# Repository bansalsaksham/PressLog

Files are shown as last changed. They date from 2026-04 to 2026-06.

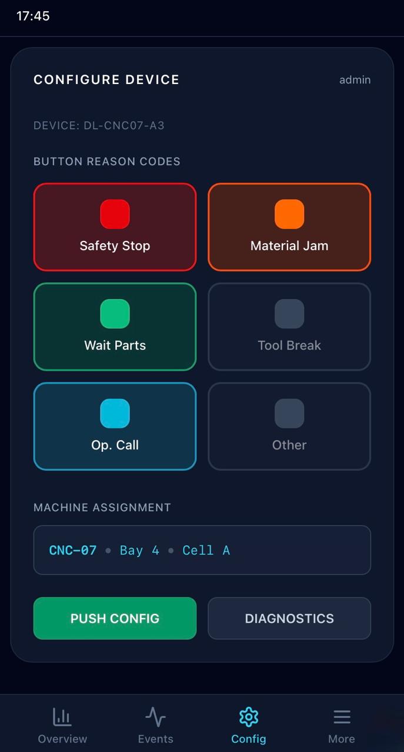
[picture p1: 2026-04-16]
Documentation/Screen 2.jpeg

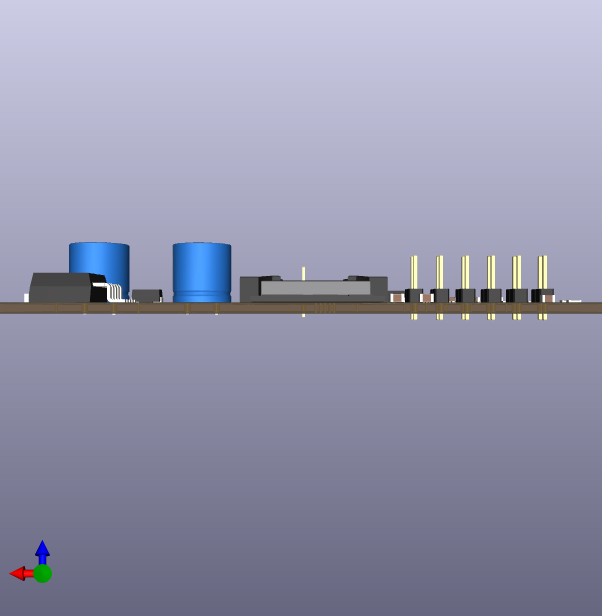
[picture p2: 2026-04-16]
Documentation/PressLog_Side.png

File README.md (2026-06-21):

# PressLog — Industrial IoT OEE Downtime Logger

A manufacturing-ready PCB and firmware architecture for capturing machine downtime reasons on a factory floor.

> **Origin:** The original design brief (see `Original Case Study Brief.pdf`) was given as a second-round technical case study during an internship interview process. I completed the full PCB design and firmware architecture independently and am sharing it here as my own project.

> **Status:** PCB design and firmware architecture complete. DRC/ERC clean, Gerbers and BOM generated for fabrication. Not yet physically built/soldered — this repository documents the design and engineering rationale, not a deployed product.

---

## 1. The Problem

OEE (Overall Equipment Effectiveness) is only as good as its data. But capturing downtime reasons at the machine edge is a human-interface problem as much as a software one. The factory floor kills conventional UX.

| Constraint | Root Cause | Why Standard Solutions Fail |
|---|---|---|
| **Gloved hands** | Thick Kevlar + metallic dust make capacitive screens useless | Tablet solutions require bare fingers: 15–30s to glove off/on. Fails the 5-second window. |
| **Patchy Wi-Fi** | VFDs, metal shielding, and RF interference create 2-hour dead zones | Cloud-first designs lose events silently. Operator never knows. OEE has invisible gaps. |
| **5-second window** | Operator moves to the next task seconds after a machine stops | Any UI requiring navigation or multiple confirmations is abandoned. |

## 2. Design Philosophy

- **Physical First** — Six large 30mm illuminated tactile buttons, one per reason code. No menus, no navigation, no scrolling. One press = one logged event, confirmed by an LED flash, an 85dB buzzer, and vibration.
- **Offline First** — Every press is timestamped via a DS3231 RTC and written to 8MB LittleFS flash *before* any network attempt. When Wi-Fi returns, the device silently replays the queue.
- **OEE Ready** — Each event carries `device_id`, `machine_id`, `reason_code`, `operator_uid` (NFC badge tap), UTC timestamp, and a sequence number. Sequence gaps are auto-detected downstream so any connectivity hole is visible to plant management.

## 3. Hardware — Custom 2-Layer PCB (KiCad)

Designed specifically for high-noise industrial environments.

| Engineering Decision | Why It Matters |
|---|---|
| **RC hardware debounce matrix** (10kΩ/0.1µF) on all 6 inputs | Software-only debouncing fails near VFDs and heavy machinery — this prevents ghost button events at the hardware level |
| **Isolated I2C routing for DS3231 RTC** | Routed completely clear of the 150kHz buck converter switching node — prevents inductive noise from corrupting timestamps. If the timestamp is wrong, the offline queue is worthless. |
| **DFM: thermal vias 0.2mm → 0.3mm** | Standard drill size reduces fabrication cost without sacrificing thermal performance |
| **RF-notched board edge** | Lets the ESP32 antenna hang off the fiberglass substrate, preventing signal attenuation |

### Physical Specifications

| Component | Specification |
|---|---|
| Platform | ESP32-S3, dual-core 240MHz |
| Buttons | 6× 30mm illuminated tactile (5N actuation) |
| Connectivity | Wi-Fi 802.11n + BLE 5.0 |
| Offline queue | 8MB LittleFS (~65,000 events) |
| RTC | DS3231, ±2ppm, coin-cell backup |
| Power | 24VDC input + 2000mAh LiPo backup (8h) |
| Identity | PN532 NFC module |

## 4. Firmware Architecture

**Offline-first data flow:**
```
Button Press → RTC Timestamp → Flash Queue (always written first) → Wi-Fi Check → Cloud Sync (batch HTTPS POST)
```

Defense-in-depth: the hardware RC filter kills high-frequency spikes; a 50ms software debounce is the secondary safety net.

```cpp
// Button ISR with secondary 50ms software debounce
void IRAM_ATTR isr_btn_0() {
  uint32_t now = millis();
  if (!pressed[0] && (now - last[0]) > 50) {
    pressed[0] = true;
    last[0] = now;
  }
}

// Queue write — always before network attempt
queueWrite(seq, rtc.now().unixtime(), buttonIdx); // flash first
confirmFeedback(buttonIdx);                       // LED + buzzer + vibration
if (wifiOnline) syncQueue();                       // attempt immediate sync
```

**Event payload schema:**
```json
{
  "device_id": "DL-CNC07-A3",
  "seq": 1042,
  "ts": "2026-04-08T14:22:08Z",
  "ts_source": "rtc",
  "reason_code": "MATERIAL_JAM",
  "reason_label": "Material Jam",
  "operator_uid": "a3f9d82c",
  "machine_id": "CNC-07"
}
```

## 5. Repository Structure

```
├── Hardware_Source/          # KiCad project — schematics + PCB layout
│   ├── ESP32_Core.kicad_sch
│   ├── HMI_IO.kicad_sch
│   ├── Power_Delivery.kicad_sch
│   ├── RTC_SubSystem.kicad_sch
│   └── PressLog_Edge_Node.kicad_pcb / .kicad_pro
├── Manufacturing/            # Fabrication-ready outputs
│   ├── PressLog_Gerbers/
│   └── PressLog_BOM.csv
├── Documentation/            # Renders, design rule reports, app mockups
│   ├── PressLog_Edge_Node.pdf
│   ├── DRC.rpt / ERC.rpt    # Design Rule Check / Electrical Rule Check — board is verified manufacturable
│   ├── PressLog_Front.png / _Back.png / _Side.png
│   └── App Interface Designs.pdf
└── Original Case Study Brief.pdf   # Full original case study writeup
```

## 6. What's Verified vs. Designed-Only

- ✅ Schematic capture across 4 subsystems (ESP32 core, HMI/IO, power delivery, RTC)
- ✅ PCB layout, routed and DRC/ERC clean
- ✅ Gerbers + BOM generated — ready to send to a fab house
- ⬜ Physical assembly / soldering — not yet built
- ⬜ Firmware — architecture and key patterns designed; not yet flashed to hardware

This was a design and engineering reasoning exercise, not a built product. The PCB design itself is real, complete, and manufacturable.

---

**Tools used:** KiCad, ESP32-S3, LittleFS, DS3231 RTC, PN532 NFC

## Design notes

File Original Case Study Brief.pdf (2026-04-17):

## Traction: Innovation Case Study

Submitted By: Saksham Bansal
GitHub Repo: https://github.com/bansalsaksham/Traction

The Problem:

OEE is only as good as its data. But capturing downtime reasons at the machine edge is a humaninterface problem as much as a software one. The factory floor kills conventional UX.
Constraint | Root Cause | Why standard solutions fail
Gloved Hands | Thick Kevlar + metallic dust make capacitive screens useless | Tablet solutions require bare fingers: 15-30s to glove off/on. Fails the 5-second window.
Patchy Wi-Fi | VFDs, metal shielding, and RF interference create 2-hour dead zones | Cloud-first designs lose events silently. Operator never knows. OEE has invisible gaps.
5-Second window | Operator moves to the next task seconds after a machine stops | Any UI requiring navigation or multiple confirmations will simply be abandoned.

Design Philosophy:

1. Physical First: Six large 30mm illuminated tactile buttons; one per reason code. No menus, no navigation, no scrolling. One press = one logged event, confirmed by an LED flash, an 85 dB buzzer, and vibration.
2. Offline First: Every press is timestamped via a DS3231 RTC and written to an 8 MB LittleFS flash BEFORE any network attempt. When Wi-Fi returns, the device silently replays the queue. The operator never needs to care whether they are online.
3. OEE Ready: Each event carries: device_id, machine_id, reason_code, operator_uid (NFC badge tap), UTC timestamp, and a sequence number. Tractian-compatible JSON. Sequence gaps are auto detected by the dashboard so any connectivity hole is visible to plant management.

Custom Hardware Implementation (PCB):

To meet the physical constraints of a machine shop, I designed a custom, manufacturing-ready 2-layer PCB in KiCad specifically engineered for high-noise industrial environments.

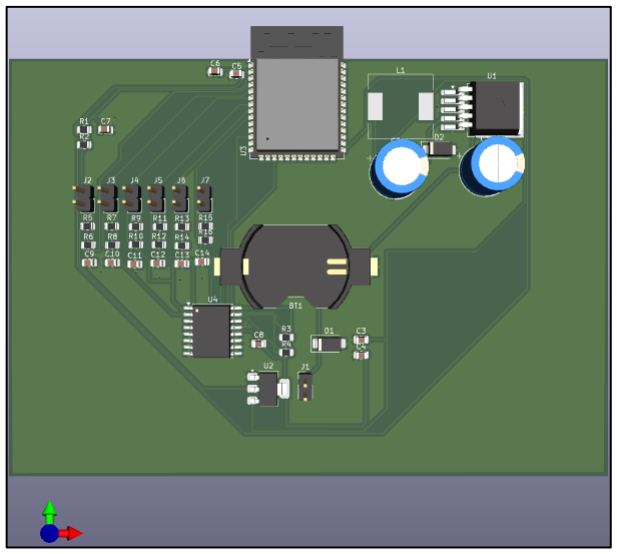
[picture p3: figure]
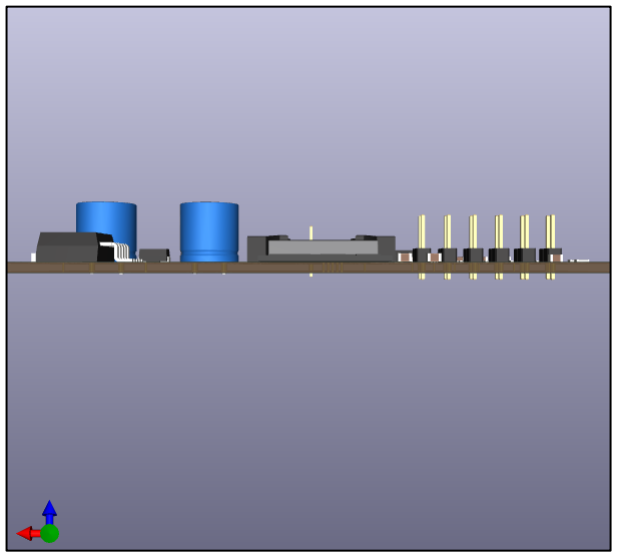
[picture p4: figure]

- Engineering for the Factory Floor:
- Hardware Debouncing (EMI Immunity): Relying on software debouncing in an environment with Variable Frequency Drives (VFDs) and heavy machinery can lead to false triggers. I designed a dedicated RC hardware debounce matrix (10kΩ/0.1µF) for all six inputs. This provides a clean, stable signal to the ESP32-S3 before processing occurs, preventing ghost events.
- Isolated Timekeeping: The core value of this device is the offline queue. If the timestamp is corrupted, the data is useless. I routed the I2C communication lines for the DS3231 RTC completely isolated from the 150kHz switching node of the onboard buck converter to prevent inductive noise interference.
- Design for Manufacturing (DFM): The board was designed for cost-effective production. I overrode the standard ESP32 footprint, expanding the thermal vias from a costly 0.2mm drill size to a standard 0.3mm, reducing fabrication costs without sacrificing thermal performance.
- RF Optimization: The board edge is specifically notched to allow the ESP32 antenna to hang off the fiberglass substrate, preventing signal attenuation and maximizing connectivity.

- Physical Specifications:
Platform | ESP32-S3 dual-core 240 MHz
Buttons | 6 x 30mm illuminated tactile (5N actuation)
Connectivity | Wi-Fi 802.11n + BLE 5.0
Offline Queue | 8 MB LittleFS (~65,000 events)
RTC | DS3231 ±2 ppm, coin-cell backup
Power | 24 VDC input + 2000 mAh LiPo backup (8h)
Identity | PN532 NFC module

Software & Firmware:

- Data Flow: Offline First Architecture

Events are written to flash BEFORE any network attempt. Zero data loss regardless of connectivity.

- Firmware: Key Patterns
- Button ISR with 50 ms hardware debounce:
- Queue write; always before network attempt:

Button Press
(Hardware
Event)

RTC
Timestamp
(UTC ISO-8601)

Flash Queue
(always written
first)

Wi-Fi Check
(Online /
Offline)

Cloud Sync
(batch HTTPS
POST)

void IRAM_ATTR isr_btn_0() { uint32_t now = millis();
if (!pressed[0] && (now - last[0]) > 50) { pressed[0] = true;
last[0] = now;
}}

queueWrite(seq, rtc.now().unixtime(), buttonIdx); // flash first confirmFeedback(buttonIdx); // LED + buzzer + vibration
if (wifiOnline) syncQueue(); // attempt immediate sync

- JSON event payload schema:
- Web Dashboard: The Three Screens

The data collected by the edge node seamlessly populates the Tractian software environment, providing plant managers with actionable insights.

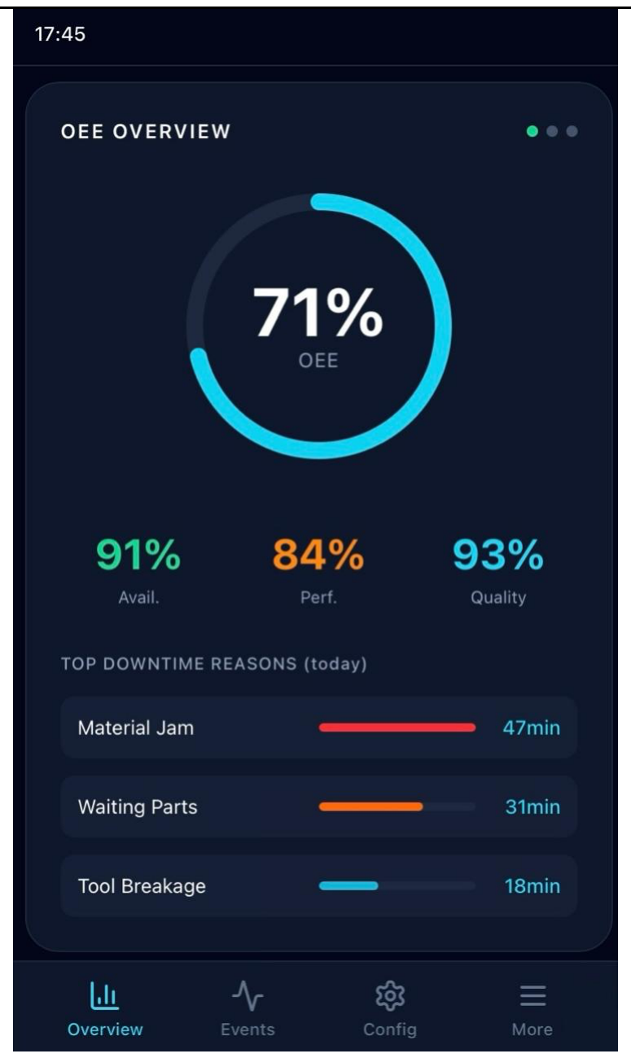
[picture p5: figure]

OEE Overview: Breaks down incoming data into true Availability, Performance, and Quality metrics, calculating the financial impact of the specific downtime reasons captured by the edge nodes.

{ "device_id": "DL-CNC07-A3", "seq": 1042,
"ts": "2026-04-08T14:22:08Z", "ts_source": "rtc",
"reason_code": "MATERIAL_JAM", "reason_label": "Material Jam", "operator_uid": "a3f9d82c", "machine_id": "CNC-07" }

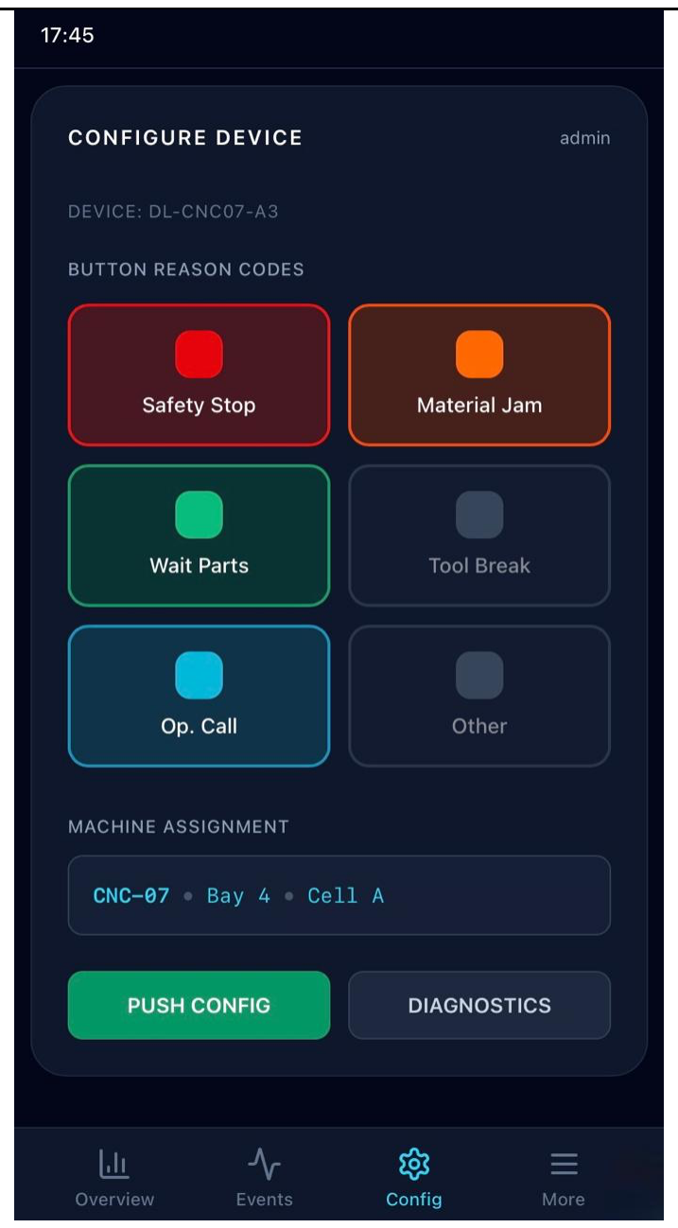
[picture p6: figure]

Device Configuration: Allows managers to assign color-coded reason codes remotely. This pushes OTA updates to the physical 6-button node on the factory floor, mapping the physical buttons to logical software categories.

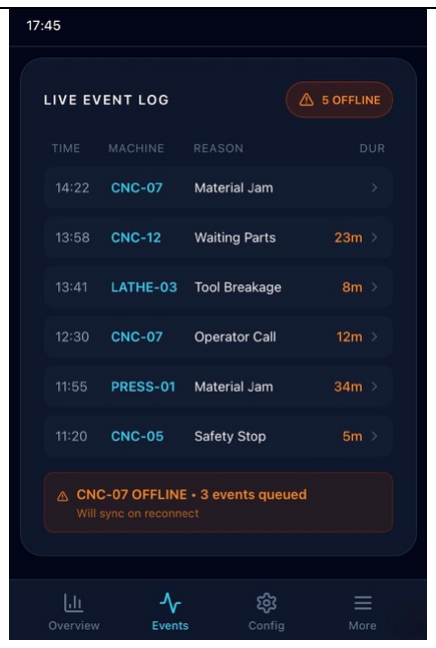
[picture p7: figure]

Live Event Log: A real-time feed of logged stops. Crucially, offline devices (like CNC-07) are clearly flagged with their queued event counts, proving the system architecture handles 2-hour network drops gracefully.

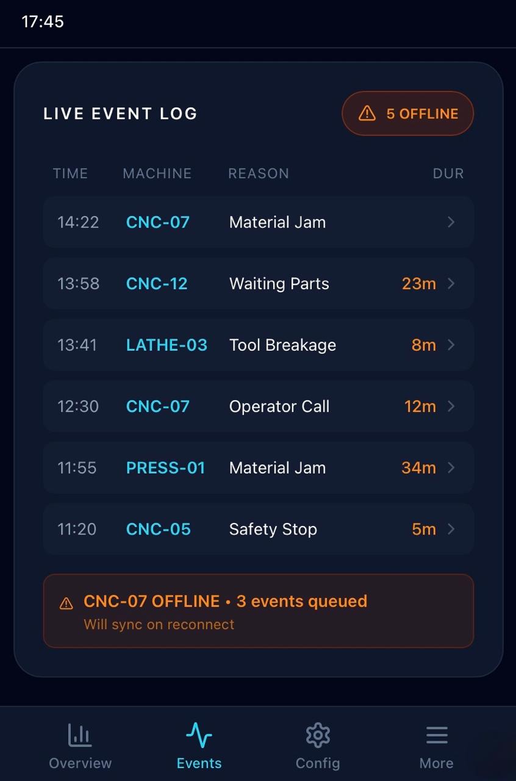
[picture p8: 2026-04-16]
Documentation/Screen 3.jpeg

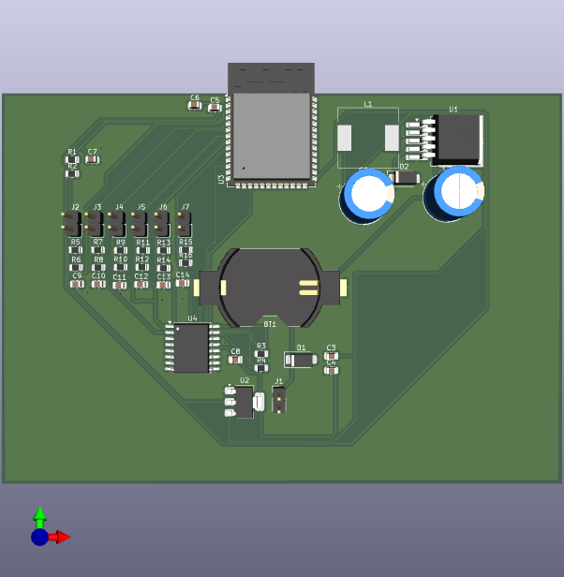
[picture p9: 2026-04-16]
Documentation/PressLog_Front.png

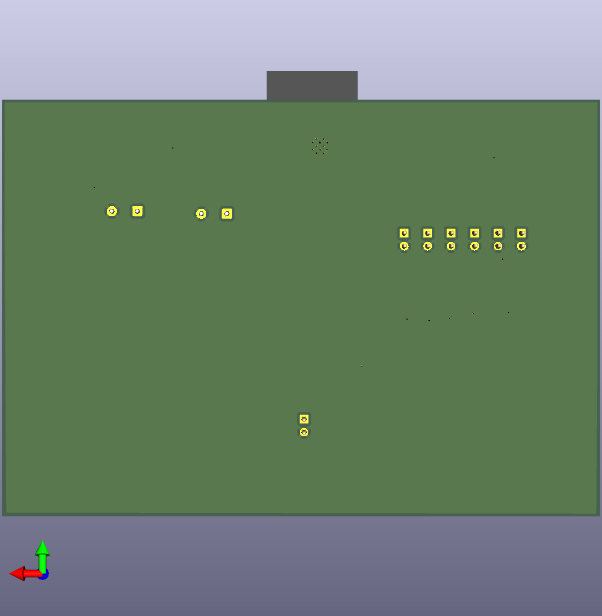
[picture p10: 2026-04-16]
Documentation/PressLog_Back.png

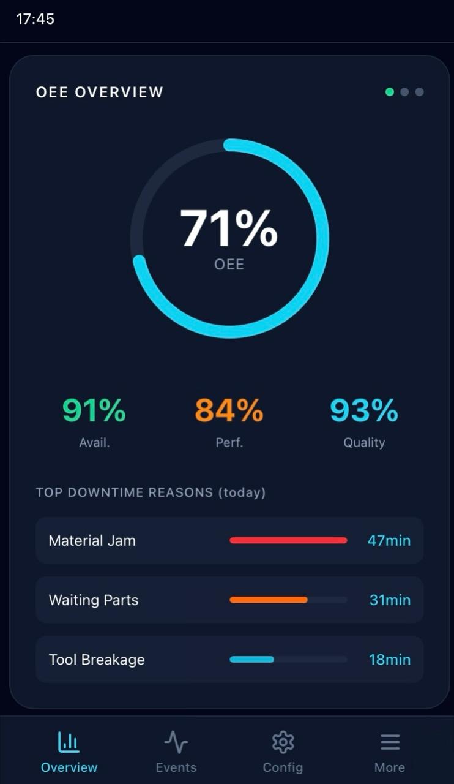
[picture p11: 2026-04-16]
Documentation/Screen 1.jpeg

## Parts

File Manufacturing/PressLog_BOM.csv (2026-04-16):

Reference | Qty | Value | DNP | Exclude from BOM | Exclude from Board | Footprint | Datasheet
BT1 | 1 | Battery_Cell |  |  |  | Battery:BatteryHolder_Keystone_1058_1x2032 | ~
C1 | 1 | 100uF |  |  |  | Capacitor_THT:CP_Radial_D10.0mm_P5.00mm | ~
C2 | 1 | 220uF |  |  |  | Capacitor_THT:CP_Radial_D10.0mm_P5.00mm | ~
C3,C4,C5 | 3 | 10uF |  |  |  | Capacitor_SMD:C_0805_2012Metric | ~
C6,C8,C9,C10,C11,C12,C13,C14 | 8 | 0.1uF |  |  |  | Capacitor_SMD:C_0805_2012Metric | ~
C7 | 1 | 1uF |  |  |  | Capacitor_SMD:C_0805_2012Metric | ~
D1 | 1 | D_TVS |  |  |  | Diode_SMD:D_SMA | ~
D2 | 1 | D_Schottky |  |  |  | Diode_SMD:D_SMA | ~
J1,J2,J3,J4,J5,J6,J7 | 7 | Conn_01x02 |  |  |  | Connector_PinHeader_2.54mm:PinHeader_1x02_P2.54mm_Vertical | ~
L1 | 1 | 33uH |  |  |  | Inductor_SMD:L_12x12mm_H6mm | ~
R1,R2 | 2 | 10kΩ |  |  |  | Resistor_SMD:R_0805_2012Metric | ~
R3,R4 | 2 | 4.7k |  |  |  | Resistor_SMD:R_0805_2012Metric | ~
R5,R6,R7,R8,R9,R10,R11,R12,R13,R14,R15,R16 | 12 | 10k |  |  |  | Resistor_SMD:R_0805_2012Metric | ~
U1 | 1 | LM2596S-5 |  |  |  | Package_TO_SOT_SMD:TO-263-5_TabPin3 | http://www.ti.com/lit/ds/symlink/lm2596.pdf
U2 | 1 | AMS1117 |  |  |  | Package_TO_SOT_SMD:SOT-223-3_TabPin2 | http://www.advanced-monolithic.com/pdf/ds1117.pdf
U3 | 1 | ESP32-S3-WROOM-1 |  |  |  | RF_Module:ESP32-S3-WROOM-1 | https://www.espressif.com/sites/default/files/documentation/esp32-s3-wroom-1_wroom-1u_datasheet_en.pdf
U4 | 1 | DS3231M |  |  |  | Package_SO:SOIC-16W_7.5x10.3mm_P1.27mm | http://datasheets.maximintegrated.com/en/ds/DS3231.pdf

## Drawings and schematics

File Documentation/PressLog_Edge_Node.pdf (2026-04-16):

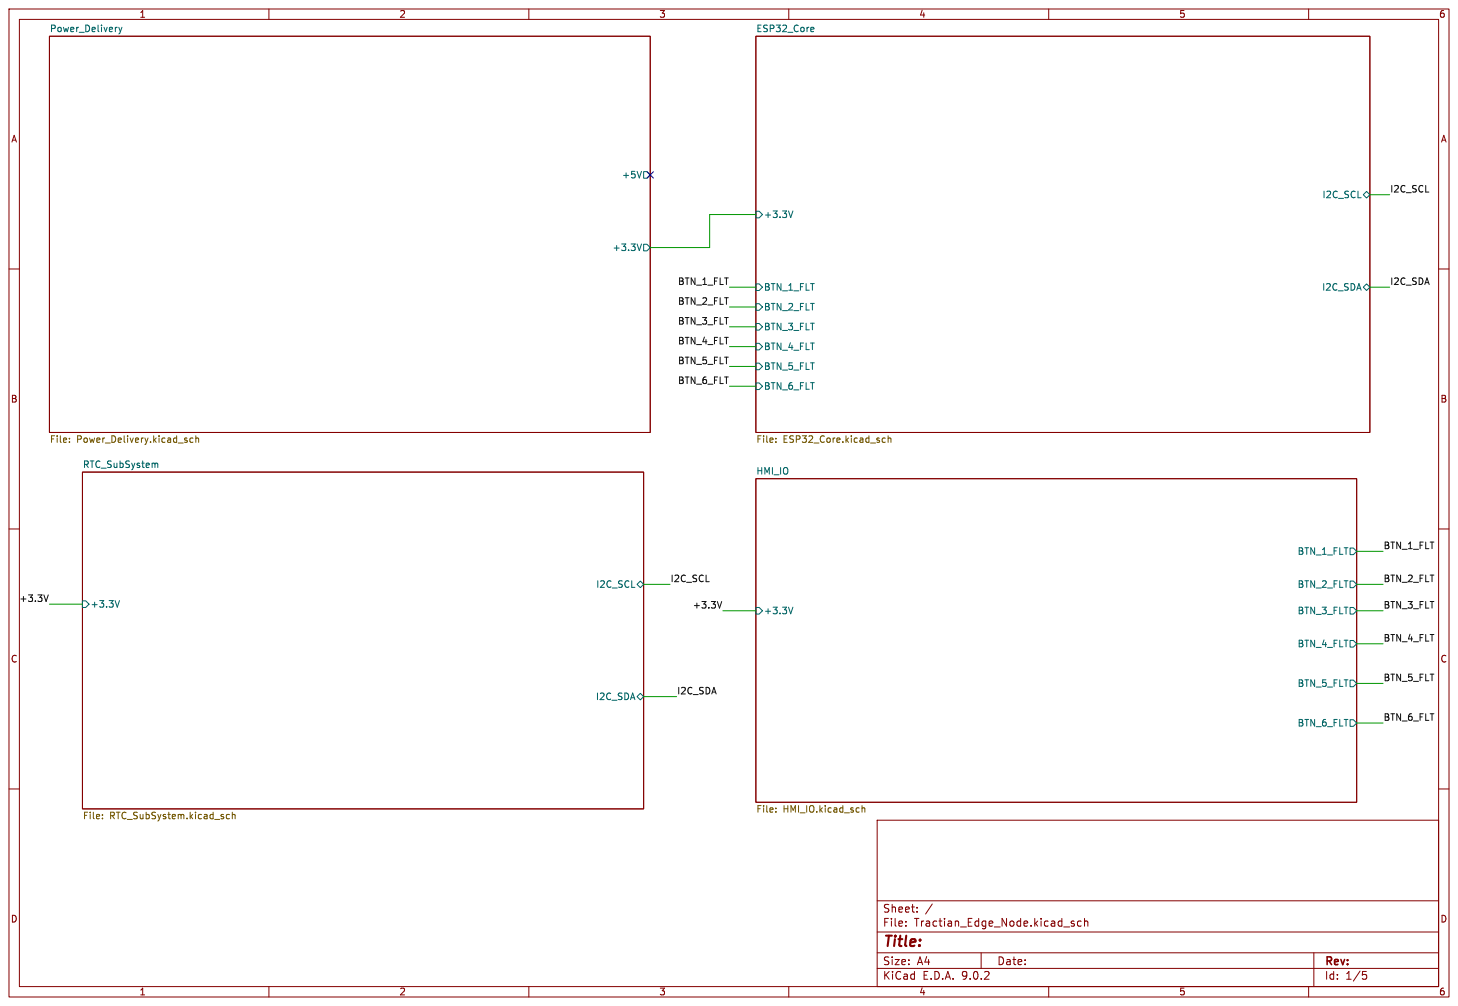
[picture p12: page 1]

Id: 1/5 Title: File: Tractian_Edge_Node.kicad_sch Sheet: / +3.3V

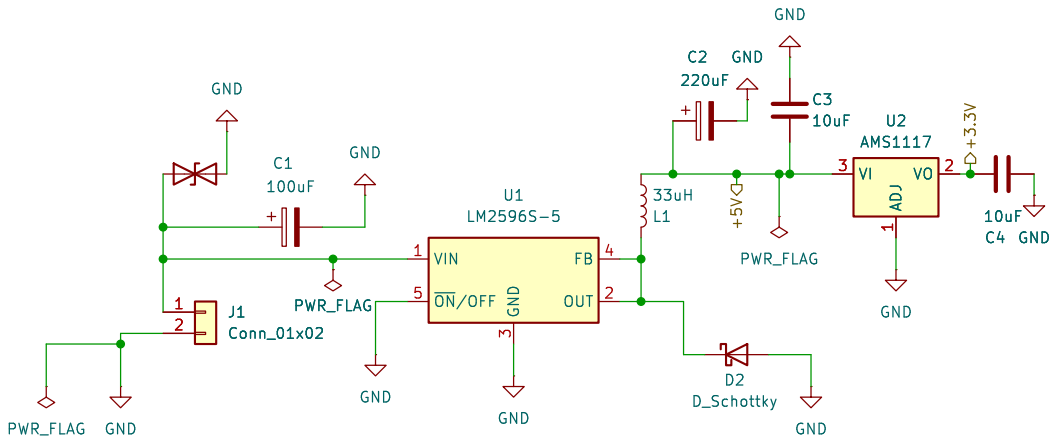
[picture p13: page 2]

Id: 2/5 Title: File: Power_Delivery.kicad_sch Sheet: /Power_Delivery/

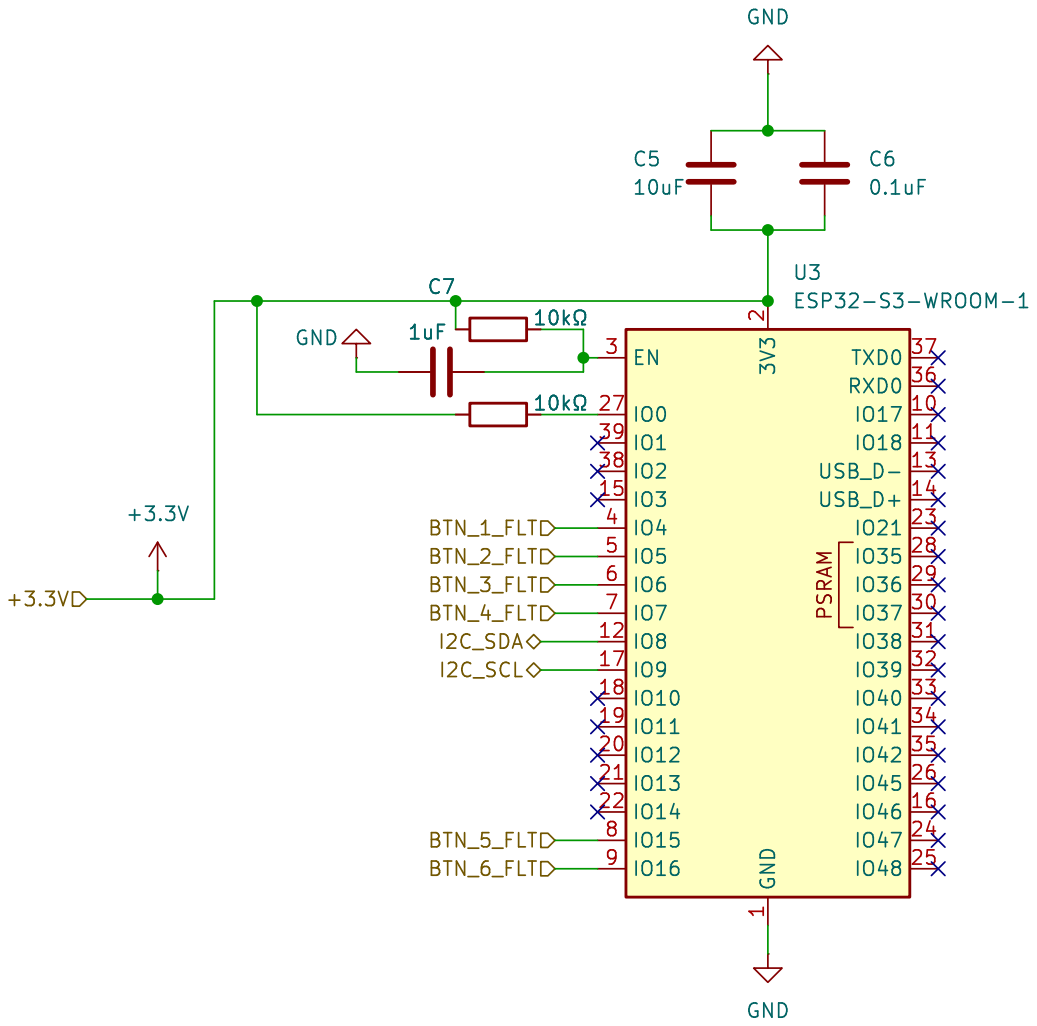
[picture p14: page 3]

Id: 3/5 Title: File: ESP32_Core.kicad_sch Sheet: /ESP32_Core/

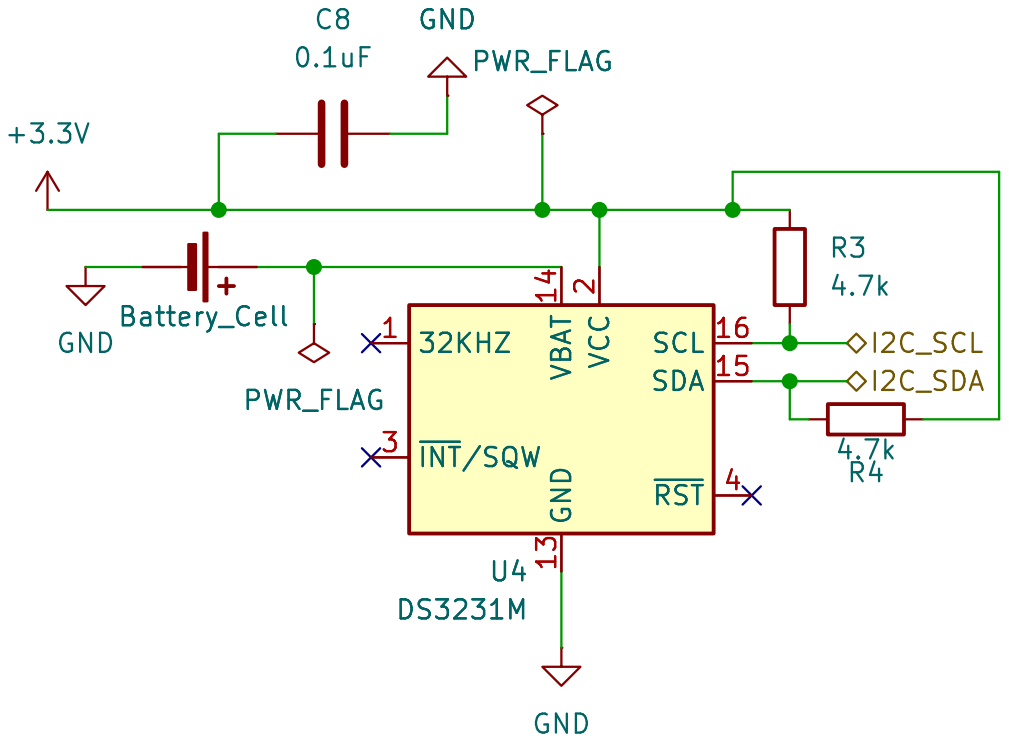
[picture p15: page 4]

Id: 4/5 Title: File: RTC_SubSystem.kicad_sch Sheet: /RTC_SubSystem/

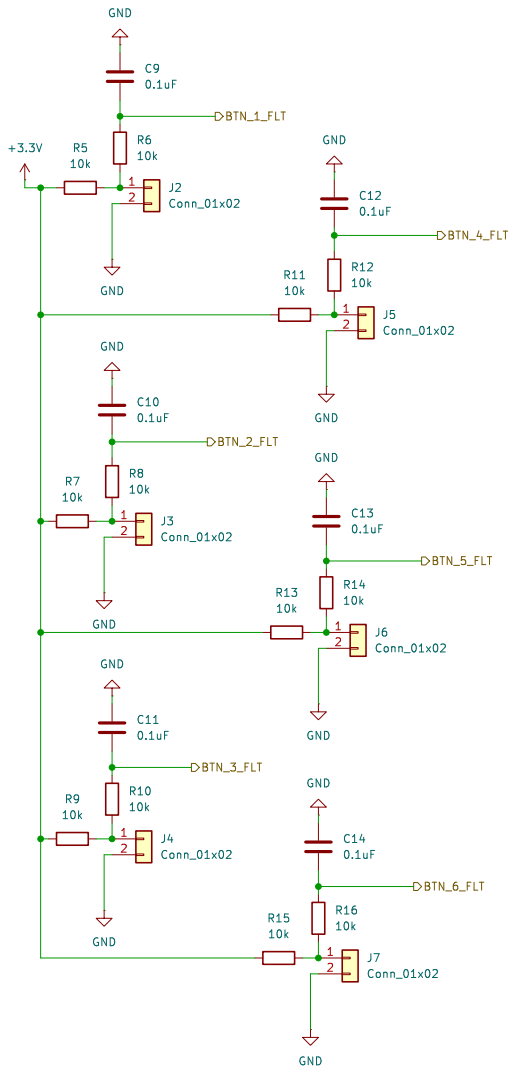
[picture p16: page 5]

Id: 5/5 Title: File: HMI_IO.kicad_sch Sheet: /HMI_IO/ GND GND 12

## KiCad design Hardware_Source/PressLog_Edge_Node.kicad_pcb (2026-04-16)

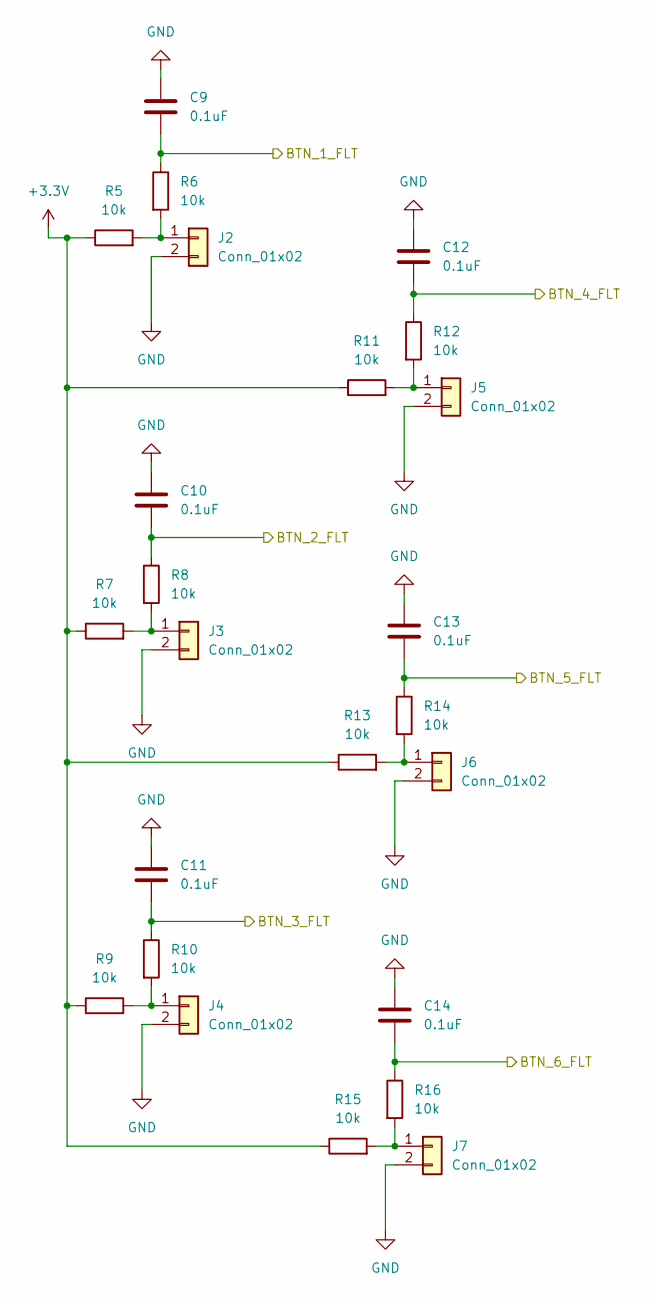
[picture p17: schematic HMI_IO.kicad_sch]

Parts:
C9, C10, C11, C12, C13, C14: 0.1uF; C_0805_2012Metric
J2, J3, J4, J5, J6, J7: Conn_01x02; PinHeader_1x02_P2.54mm_Vertical
R5, R6, R7, R8, R9, R10, R11, R12, R13, R14, R15, R16: 10k; R_0805_2012Metric

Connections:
+3.3V: R5.1, R7.1, R9.1, R11.1, R13.1, R15.1; also elsewhere on the board
/BTN_1_FLT: C9.2, R6.1; also elsewhere on the board
/BTN_2_FLT: C10.2, R8.1; also elsewhere on the board
/BTN_3_FLT: C11.2, R10.1; also elsewhere on the board
/BTN_4_FLT: C12.2, R12.1; also elsewhere on the board
/BTN_5_FLT: C13.2, R14.1; also elsewhere on the board
/BTN_6_FLT: C14.2, R16.1; also elsewhere on the board
GND: C9.1, C10.1, C11.1, C12.1, C13.1, C14.1, J2.2, J3.2, J4.2, J5.2, J6.2, J7.2; also elsewhere on the board
unnamed: J2.1, R5.2, R6.2
unnamed: J3.1, R7.2, R8.2
unnamed: J4.1, R9.2, R10.2
unnamed: J5.1, R11.2, R12.2
unnamed: J6.1, R13.2, R14.2
unnamed: J7.1, R15.2, R16.2

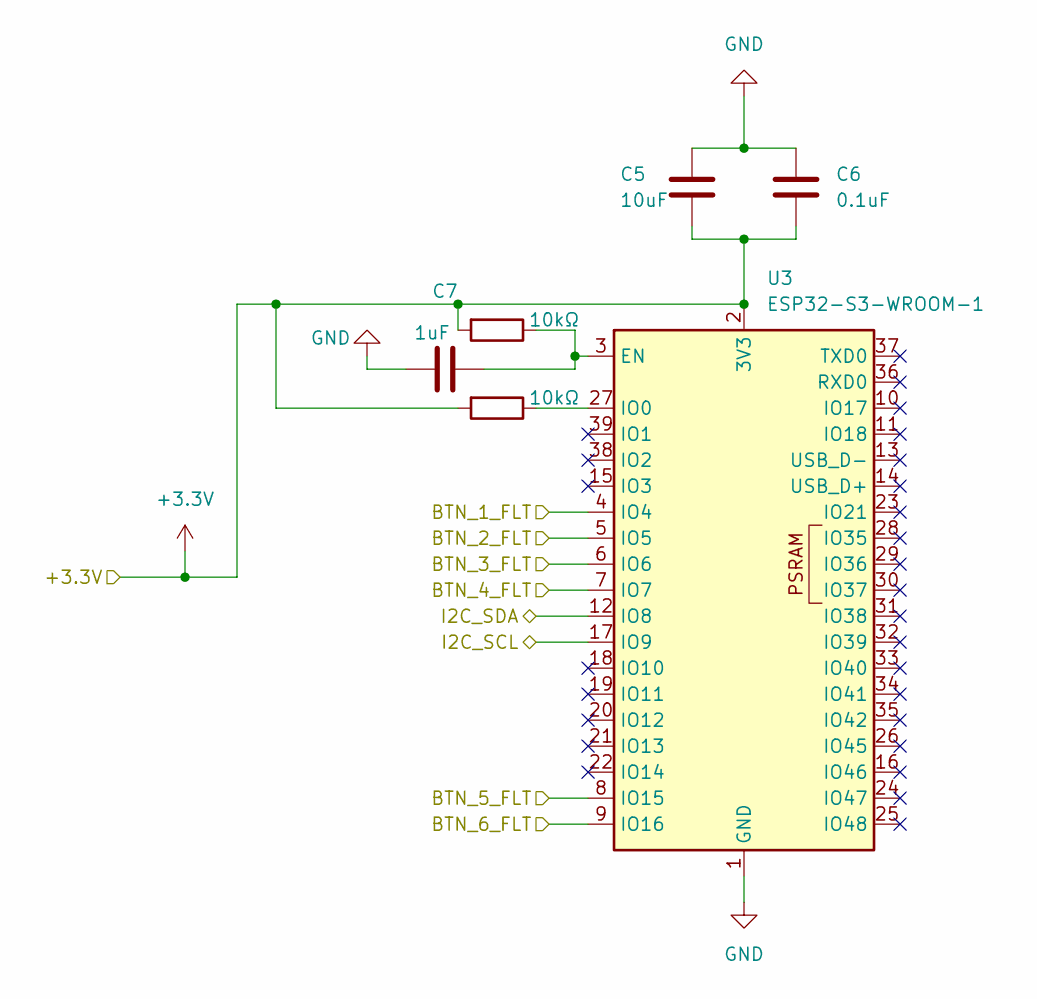
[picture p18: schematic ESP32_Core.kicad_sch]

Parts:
C5: 10uF; C_0805_2012Metric
C6: 0.1uF; C_0805_2012Metric
C7: 1uF; C_0805_2012Metric
R1, R2: 10kΩ; R_0805_2012Metric
U3: ESP32-S3-WROOM-1

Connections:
+3.3V: C5.2, C6.2, R1.2, R2.2, U3.2 (3V3); also elsewhere on the board
/BTN_1_FLT: U3.4 (IO4); also elsewhere on the board
/BTN_2_FLT: U3.5 (IO5); also elsewhere on the board
/BTN_3_FLT: U3.6 (IO6); also elsewhere on the board
/BTN_4_FLT: U3.7 (IO7); also elsewhere on the board
/BTN_5_FLT: U3.8 (IO15); also elsewhere on the board
/BTN_6_FLT: U3.9 (IO16); also elsewhere on the board
/I2C_SCL: U3.17 (IO9); also elsewhere on the board
/I2C_SDA: U3.12 (IO8); also elsewhere on the board
GND: C5.1, C6.1, C7.2, U3.1 (GND), U3.40 (GND), U3.41 (GND); also elsewhere on the board
unnamed: C7.1, R1.1, U3.3 (EN)
unnamed: R2.1, U3.27 (IO0)

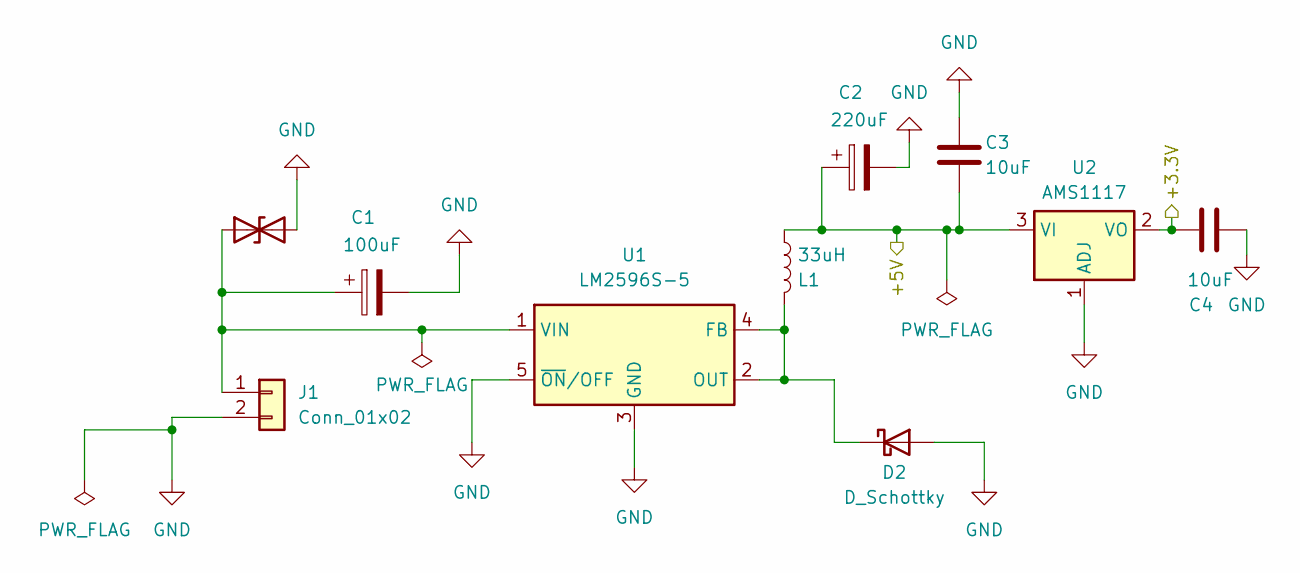
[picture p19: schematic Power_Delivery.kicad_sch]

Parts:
C1: 100uF; CP_Radial_D10.0mm_P5.00mm
C2: 220uF; CP_Radial_D10.0mm_P5.00mm
C3, C4: 10uF; C_0805_2012Metric
D1: D_TVS; D_SMA
D2: D_Schottky; D_SMA
J1: Conn_01x02; PinHeader_1x02_P2.54mm_Vertical
L1: 33uH; L_12x12mm_H6mm
U1: LM2596S-5; TO-263-5_TabPin3
U2: AMS1117; SOT-223-3_TabPin2

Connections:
+3.3V: C4.2, U2.2 (VO); also elsewhere on the board
/Power_Delivery/+5V: C2.1, C3.2, L1.2, U2.3 (VI)
GND: C1.2, C2.2, C3.1, C4.1, D1.2 (A2), D2.2 (A), J1.2, U1.3 (GND), U1.5 (~ON/OFF), U2.1 (ADJ); also elsewhere on the board
unnamed: C1.1, D1.1 (A1), J1.1, U1.1 (VIN)
unnamed: D2.1 (K), L1.1, U1.2 (OUT), U1.4 (FB)

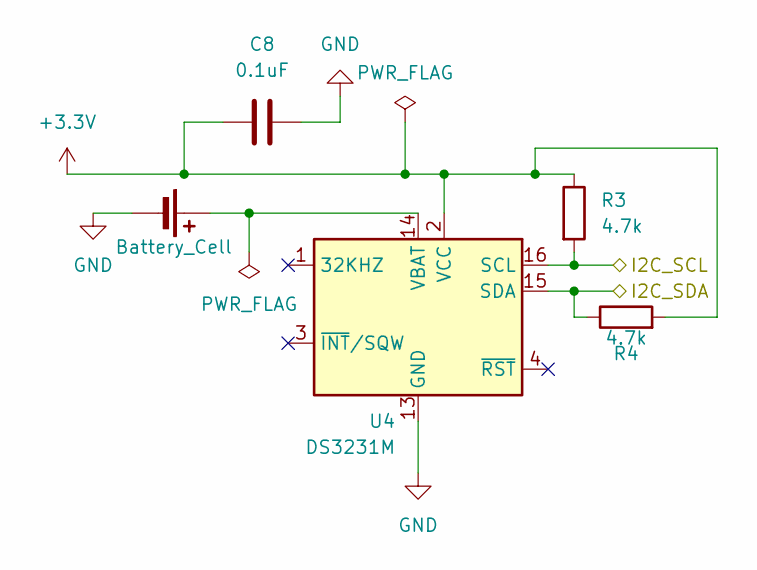
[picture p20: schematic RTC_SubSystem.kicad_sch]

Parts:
BT1: Battery_Cell; BatteryHolder_Keystone_1058_1x2032
C8: 0.1uF; C_0805_2012Metric
R3, R4: 4.7k; R_0805_2012Metric
U4: DS3231M; SOIC-16W_7.5x10.3mm_P1.27mm

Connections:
+3.3V: C8.2, R3.1, R4.2, U4.2 (VCC); also elsewhere on the board
/I2C_SCL: R3.2, U4.16 (SCL); also elsewhere on the board
/I2C_SDA: R4.1, U4.15 (SDA); also elsewhere on the board
GND: BT1.2 (-), C8.1, U4.5 (GND), U4.6 (GND), U4.7 (GND), U4.8 (GND), U4.9 (GND), U4.10 (GND), U4.11 (GND), U4.12 (GND), U4.13 (GND); also elsewhere on the board
unnamed: BT1.1 (+), U4.14 (VBAT)

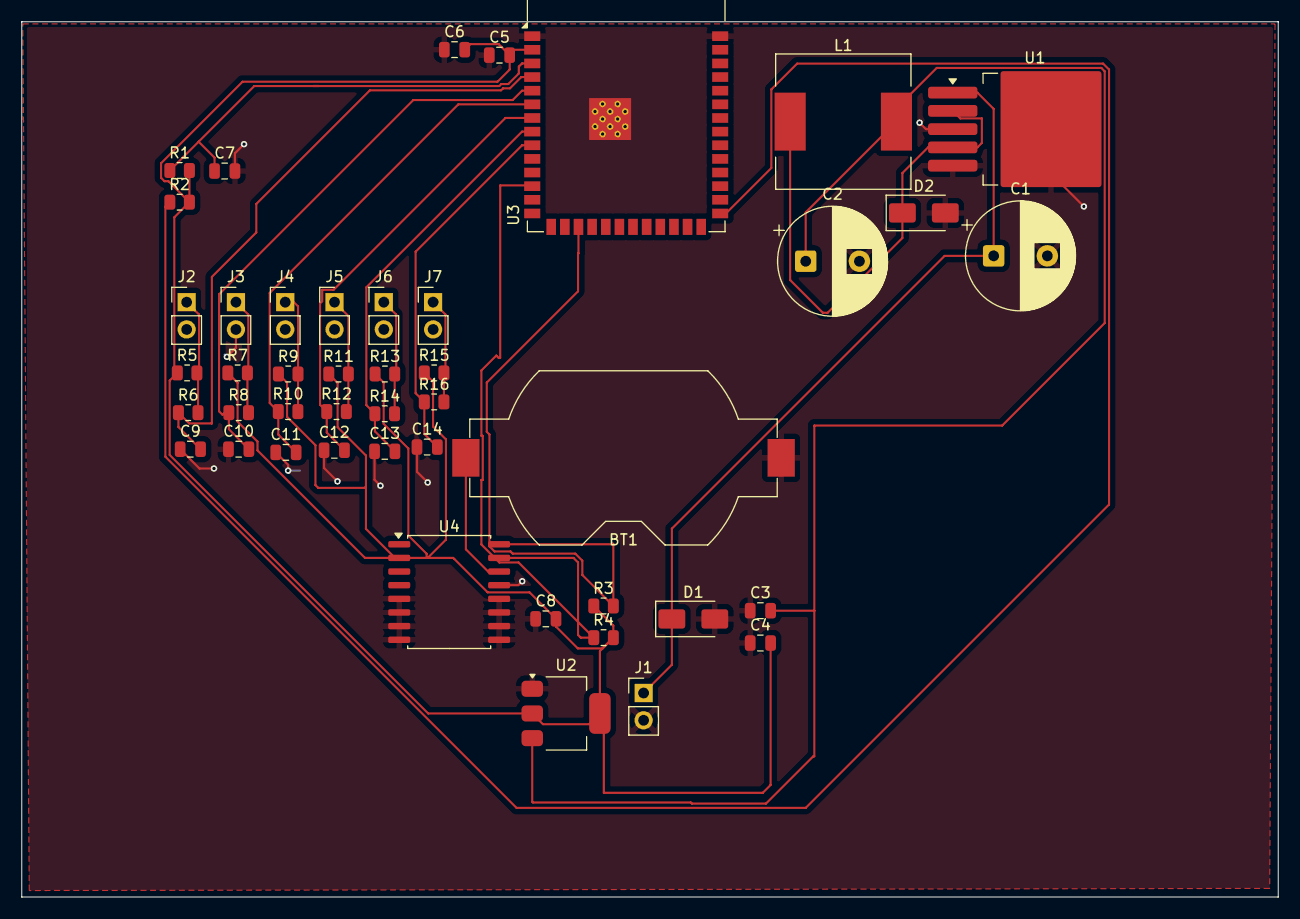
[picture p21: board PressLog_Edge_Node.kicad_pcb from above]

Board: 2 copper layers, 117.0 x 81.5 mm, 45 parts (0 on the bottom side), 22 nets.
